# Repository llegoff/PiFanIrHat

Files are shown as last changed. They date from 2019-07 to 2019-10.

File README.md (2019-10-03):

[:fr:](LISEZMOI.md) [:uk:](README.md)

buy rev1 on [ebay](https://www.ebay.fr/itm/153597547428) :package:

buy rev1 (silent fan) on [ebay](https://www.ebay.fr/itm/153600642463) :package:

# PiFanIrHat

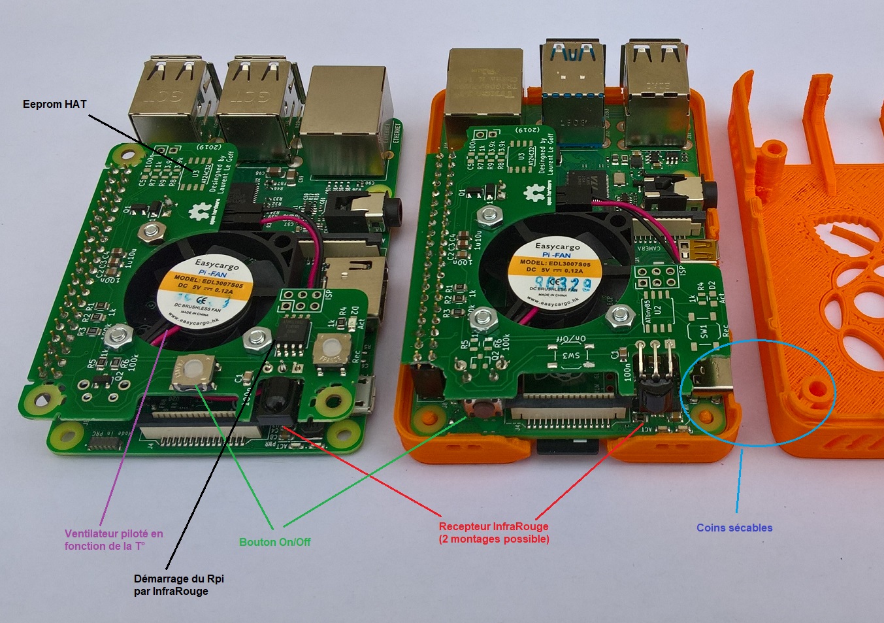
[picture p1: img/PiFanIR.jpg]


### Fan

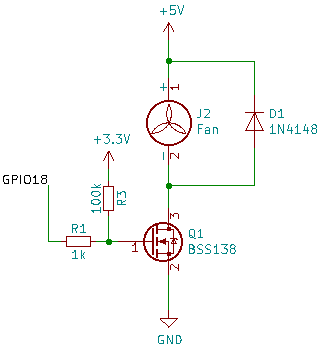
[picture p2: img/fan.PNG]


:warning: need raspbian buster, good version of gpio-fan overlay, come with kernel 4.19.

configuration: edit /boot/config.txt, add folowing line

    dtoverlay=gpio-fan,gpiopin=18,temp=55000

### On/Off button

on/off button is connected to gpio3 and GND

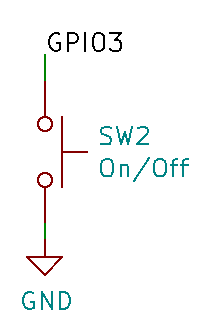
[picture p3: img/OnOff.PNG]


configuration: edit /boot/config.txt, add folowing line

    dtoverlay=gpio-shutdown,gpio_pin=3,active_low=1,gpio_pull=up
    
:warning: on raspberry pi 4, only shutdown work, with original bootloader. For power on, bootloader need to be update to ~~RC3.3~~ last version (see https://www.raspberrypi.org/forums/viewtopic.php?f=117&t=246027)

Download the last bootloader at recovery section https://www.raspberrypi.org/downloads/

### IR receiver

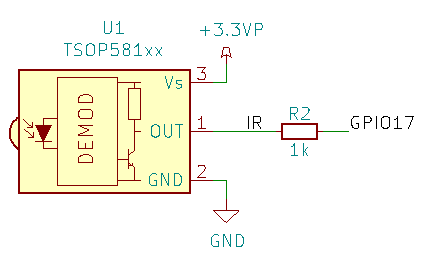
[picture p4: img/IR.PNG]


install ir-keytable

    sudo apt install ir-keytable

configuration: edit /boot/config.txt, add folowing line

    dtoverlay=gpio-ir,gpio_pin=17,gpio_pull=1,rc-map-name=<keymap file for your remote>

keymap files path is /lib//udev/rc_keymaps/

test remote

    sudo ir-keytable -t -v -p all

### IR power On

:warning: on raspberry pi 4, only shutdown work, with original bootloader. For power on, bootloader need to be update to ~~RC3.3~~ last version (see https://www.raspberrypi.org/forums/viewtopic.php?f=117&t=246027)

Download the last bootloader at recovery section https://www.raspberrypi.org/downloads/

:grey_exclamation: For key learning, press Rec button, led stay on, press remote key, led return off.

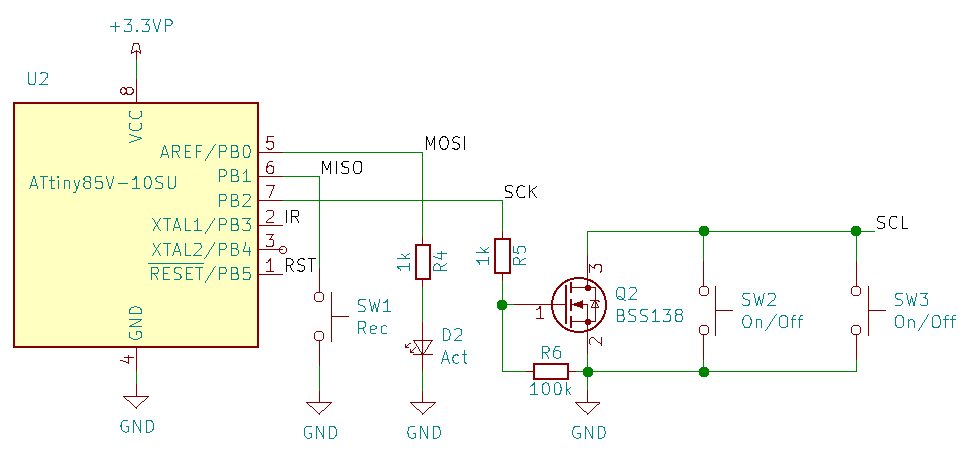
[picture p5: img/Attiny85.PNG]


flash Attiny85 with file [PiFanIr.hex](attiny85/PiFanIr.hex?raw=true)

    avrdude -p attiny85 -P COM5 -b 19200 -c avrisp -u -U flash:w:PiFanIr.hex

flash attiny85 fuses : lfuse:E2 , efuse:FF , hfuse:DF

    avrdude -p attiny85 -P COM5 -b 19200 -c avrisp -u -U lfuse:w:0xe2:m -U hfuse:w:0xdf:m -U efuse:w:0xff:m

## PCB
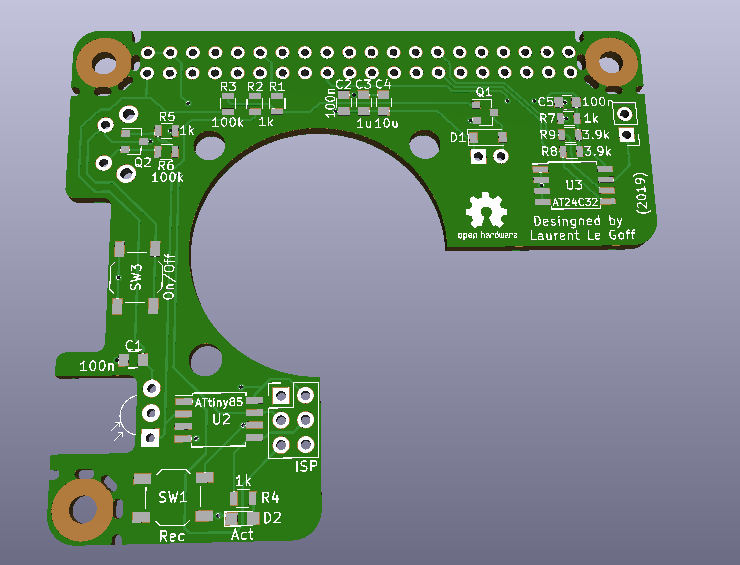
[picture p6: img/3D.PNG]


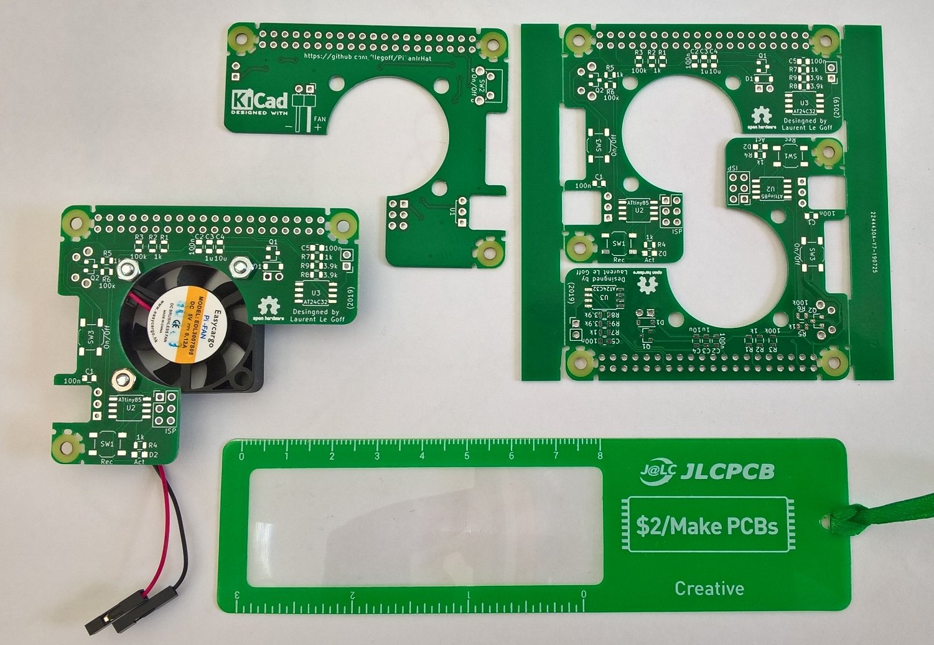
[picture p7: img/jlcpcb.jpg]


## Schematic
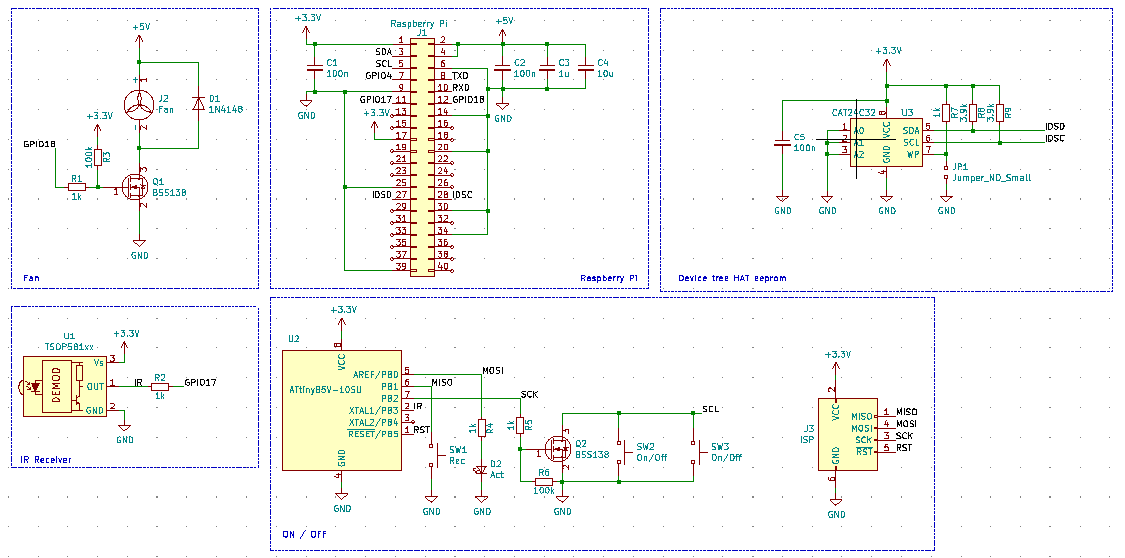
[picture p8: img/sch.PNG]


## Révision
rev1
- bad footprint for eeprom

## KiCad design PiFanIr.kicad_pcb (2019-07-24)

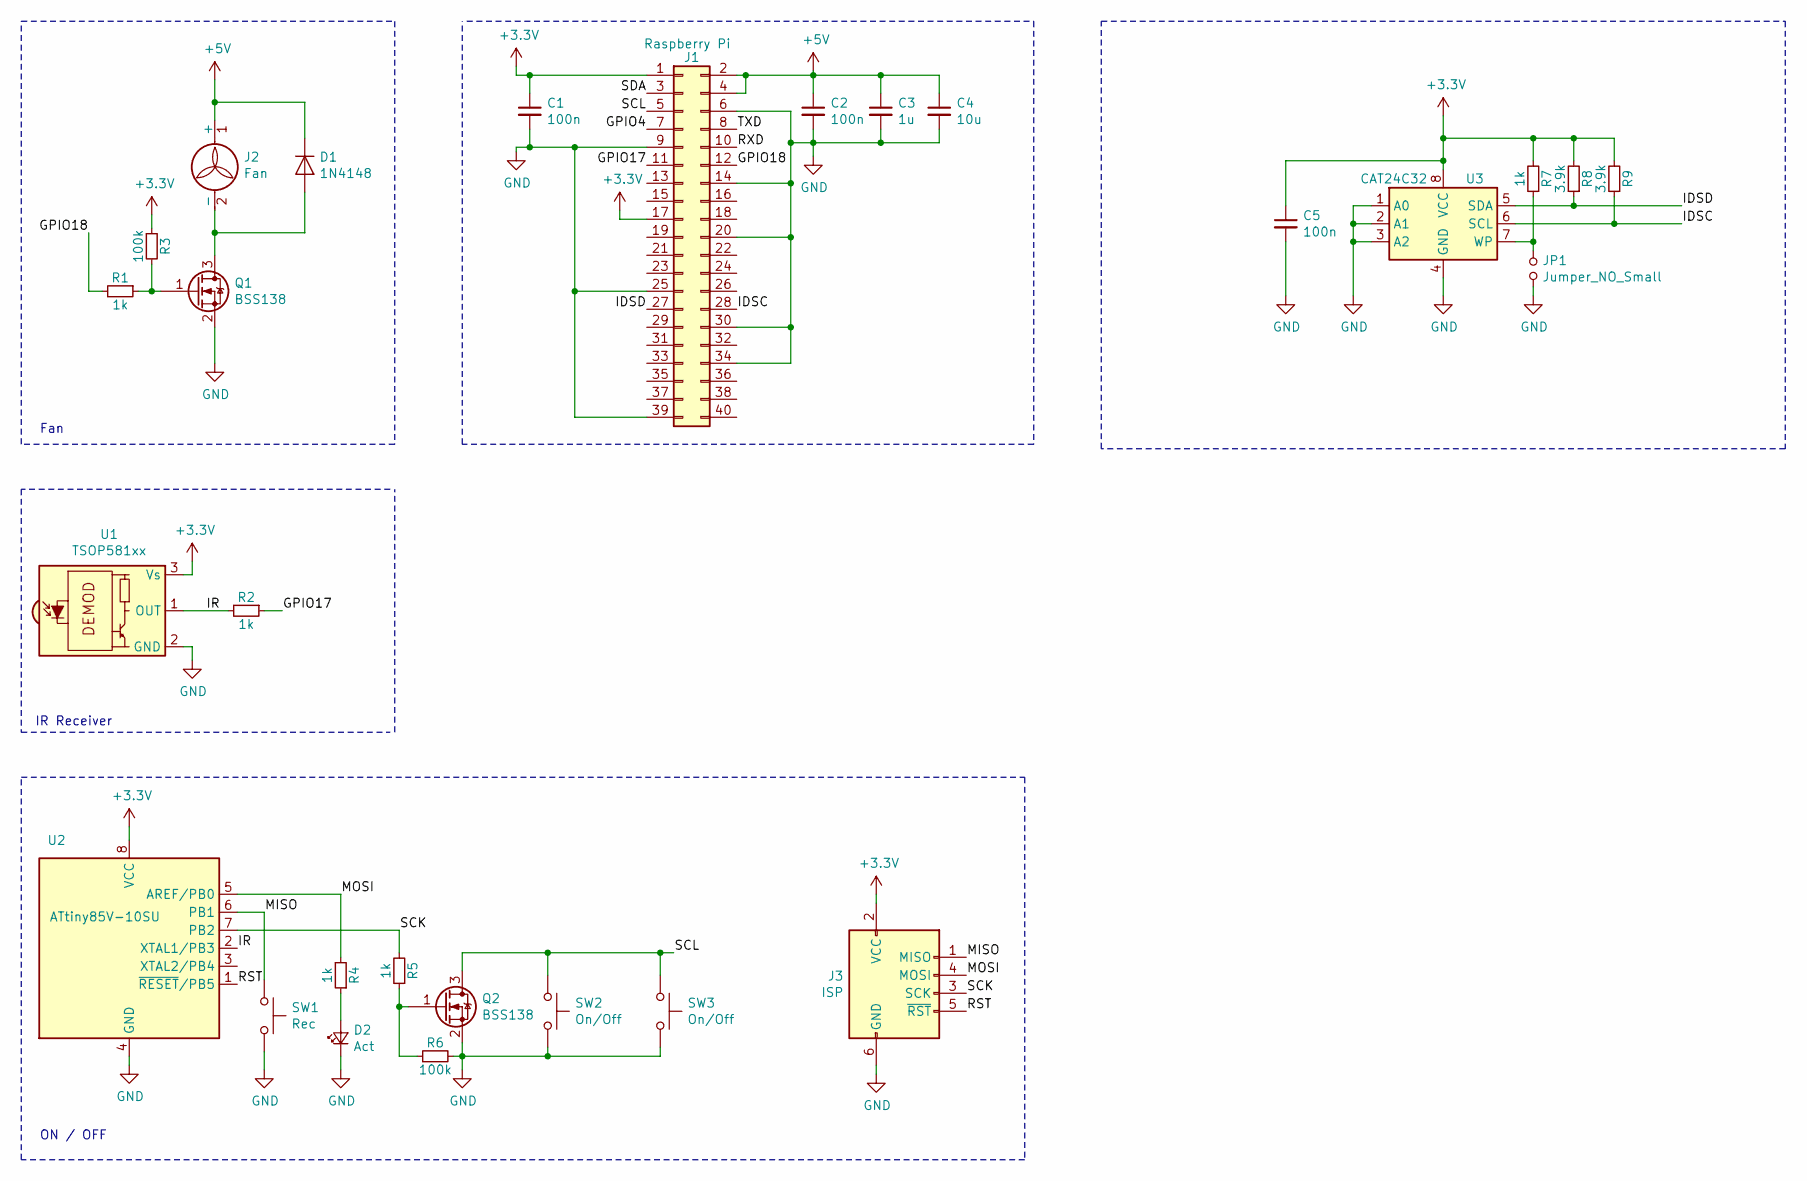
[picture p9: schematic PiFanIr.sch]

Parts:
C1, C2, C5: 100n; C_0805
C3: 1u; C_0805
C4: 10u; C_0805
D1: 1N4148; D_SOD-123
D2: Act; LED_0805
J1: Raspberry Pi; RaspberryPiHAT
J2: Fan; Pin_Header_Angled_1x02_Pitch2.54mm
J3: ISP; Pin_Header_Straight_2x03_Pitch2.54mm
JP1: Jumper_NO_Small; Pin_Header_Straight_1x02_Pitch2.54mm
Q1, Q2: BSS138; SOT-23
R1, R2, R4, R5, R7: 1k; R_0805
R3, R6: 100k; R_0805
R8, R9: 3.9k; R_0805
SW1: Rec; SW_SPST_TL3342
SW2: On/Off; SW_Tactile_SPST_Angled_PTS645Vx31-2LFS
SW3: On/Off; SW_SPST_TL3342
U1: TSOP581xx; IRReceiver_Vishay_MINICAST-3pin
U2: ATtiny85V-10SU; SOIJ-8_5.3x5.3mm_Pitch1.27mm
U3: CAT24C32; SOIJ-8_5.3x5.3mm_Pitch1.27mm

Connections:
+3V3: C1.1, C5.1, J1.1, J1.17, J3.2 (VCC), R3.1, R7.2, R8.2, R9.2, U1.3 (Vs), U2.8 (VCC), U3.8 (VCC)
+5V: C2.1, C3.1, C4.1, D1.1 (K), J1.2, J1.4, J2.1 (+)
/GPIO4: J1.7
/GPIO17: J1.11, R2.1
/GPIO18: J1.12, R1.2
/IDSC: J1.28, R9.1, U3.6 (SCL)
/IDSD: J1.27, R8.1, U3.5 (SDA)
/IR: R2.2, U1.1 (OUT), U2.2 (XTAL1/PB3)
/MISO: J3.1 (MISO), SW1.1, U2.6 (PB1)
/MOSI: J3.4 (MOSI), R4.2, U2.5 (AREF/PB0)
/RST: J3.5 (~RST), U2.1 (~RESET~/PB5)
/RXD: J1.10
/SCK: J3.3 (SCK), R5.2, U2.7 (PB2)
/SCL: J1.5, Q2.3 (D), SW2.1, SW3.1
/SDA: J1.3
/TXD: J1.8
GND: C1.2, C2.2, C3.2, C4.2, C5.2, D2.1 (K), J1.6, J1.9, J1.14, J1.20, J1.25, J1.30, J1.34, J1.39, J3.6 (GND), JP1.2, Q1.2 (S), Q2.2 (S), R6.2, SW1.2, SW2.2, SW3.2, U1.2 (GND), U2.4 (GND), U3.1 (A0), U3.2 (A1), U3.3 (A2), U3.4 (GND)
unnamed: D1.2 (A), J2.2 (-), Q1.3 (D)
unnamed: D2.2 (A), R4.1
unnamed: JP1.1, R7.1, U3.7 (WP)
unnamed: Q1.1 (G), R1.1, R3.2
unnamed: Q2.1 (G), R5.1, R6.1

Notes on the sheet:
Fan
IR Receiver
ON / OFF

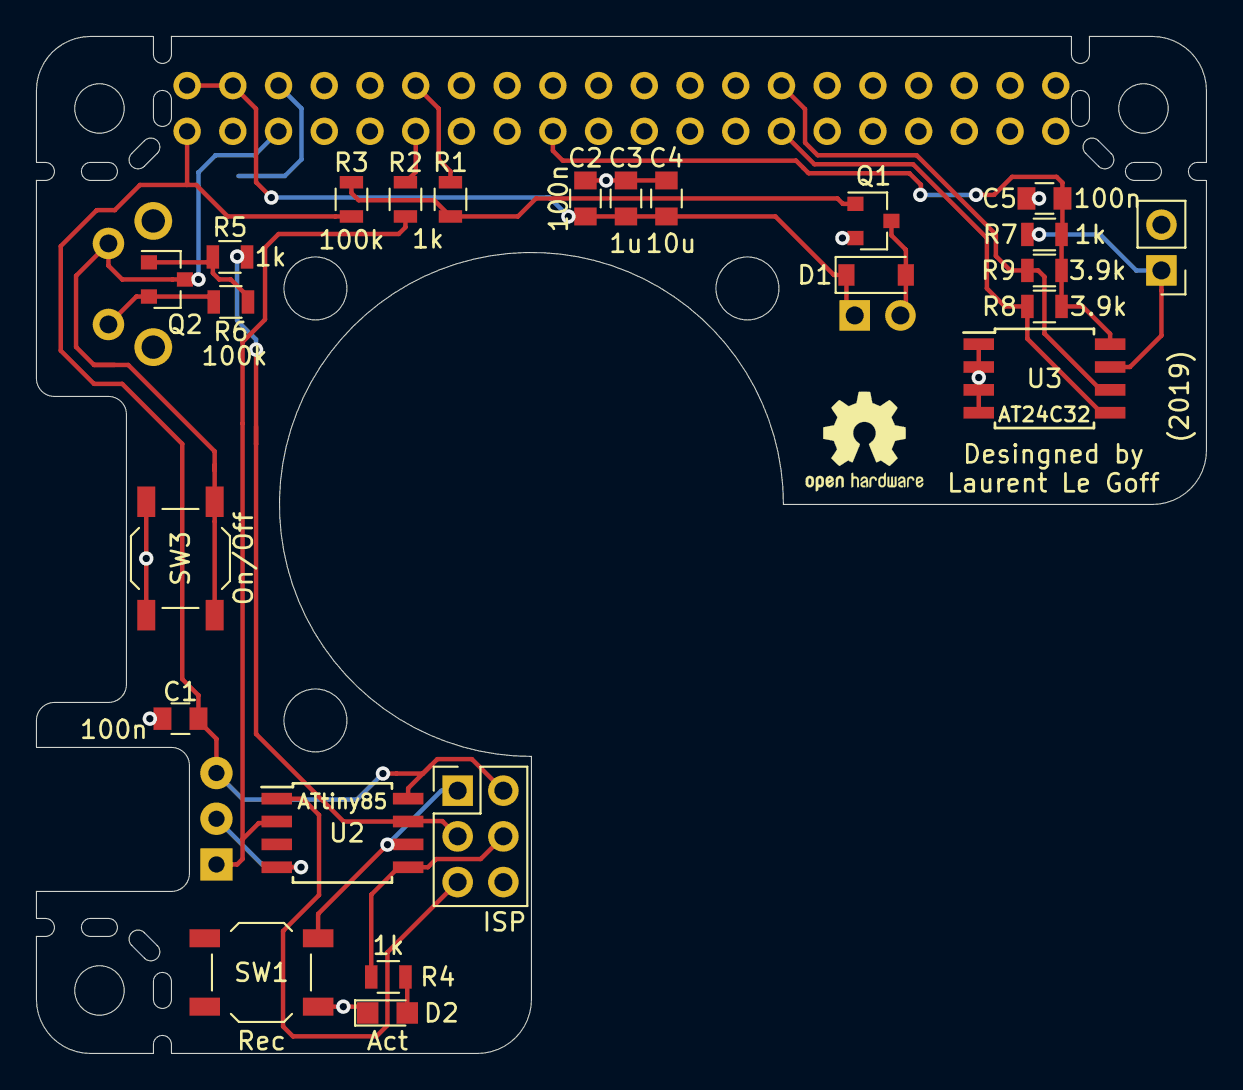
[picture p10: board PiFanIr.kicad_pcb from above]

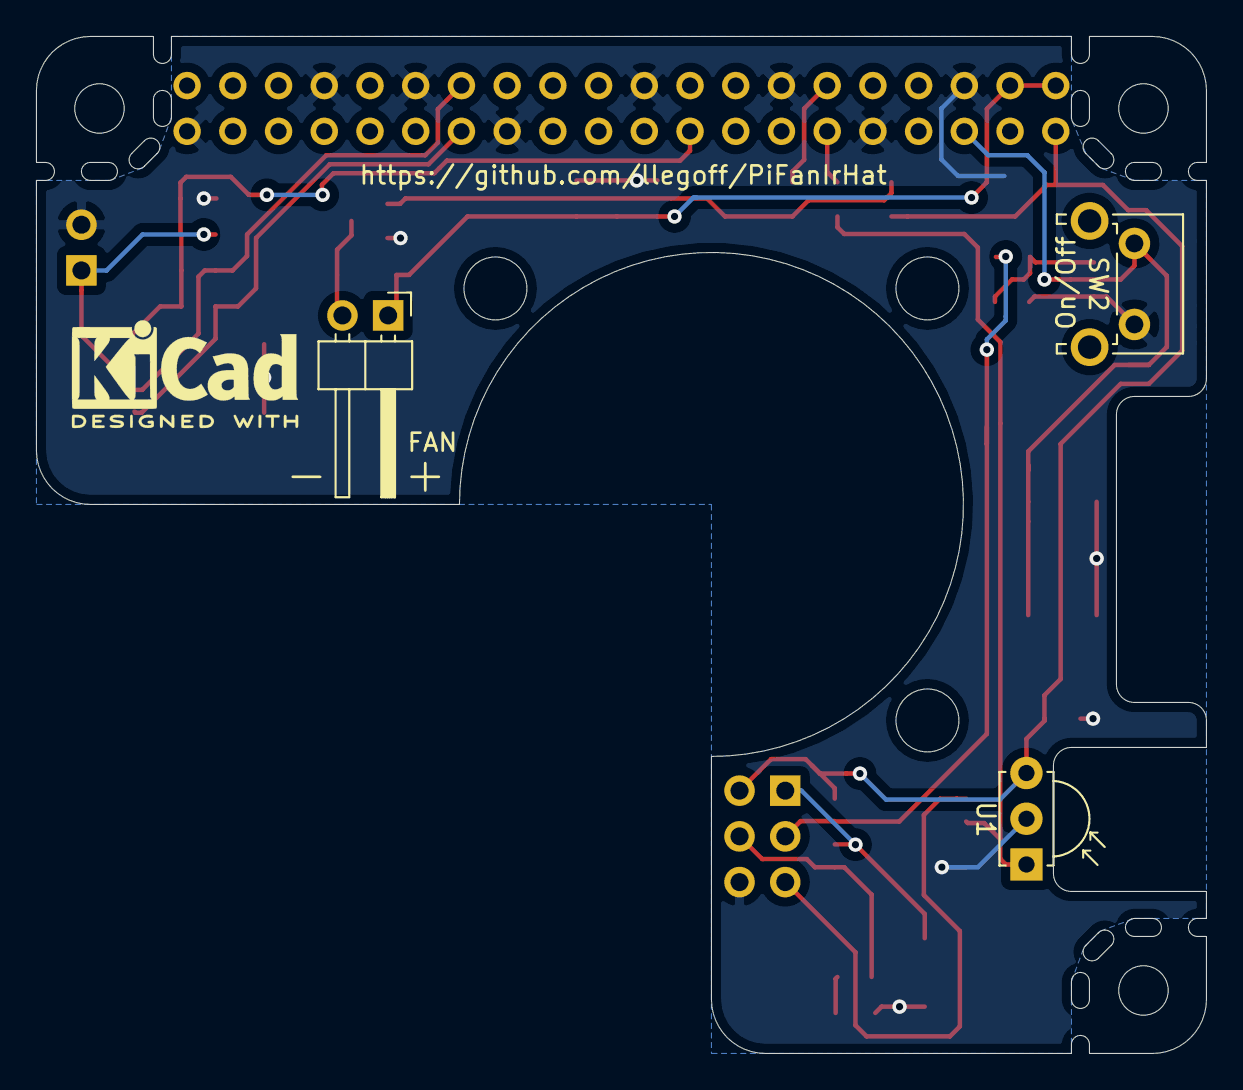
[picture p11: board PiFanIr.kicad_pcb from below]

Board: 2 copper layers, 65.0 x 56.5 mm, 28 parts (3 on the bottom side), 18 nets.

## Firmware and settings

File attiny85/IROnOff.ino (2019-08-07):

/*

 */

#include <IRremote.h> //https://github.com/z3t0/Arduino-IRremote
#include <EEPROM.h>

#define RECV_PIN  3
#define RELAY_PIN  2
#define LED_PIN  0
#define SW_PIN  1


IRrecv irrecv(RECV_PIN);
decode_results results;

unsigned long good_code;
unsigned long i;


void setup()
{
  pinMode(RELAY_PIN, OUTPUT);
  pinMode(LED_PIN, OUTPUT);
  pinMode(SW_PIN,INPUT_PULLUP);
  irrecv.enableIRIn(); // Start the receiver
  pinMode(RECV_PIN,INPUT_PULLUP);
  EEPROM.get(0, good_code); //read in eeprom
}


void loop() {
  if (irrecv.decode(&results)) {
    if (results.value==good_code){
        digitalWrite(RELAY_PIN,HIGH);
        digitalWrite(LED_PIN,HIGH);
    }
    irrecv.resume(); // Receive the next value
    i=50000;
    while (i--){;}    
    digitalWrite(RELAY_PIN,LOW);
    digitalWrite(LED_PIN,LOW);
  }
  // Key learning
  if (!digitalRead(SW_PIN)){
      digitalWrite(LED_PIN,HIGH);
      while (!irrecv.decode(&results)) { ;}
      EEPROM.put(0,results.value);//save in eeprom
      irrecv.resume(); // Receive the next value
      EEPROM.get(0, good_code); //read in eeprom
      digitalWrite(LED_PIN,LOW);
  } //end learning
}
